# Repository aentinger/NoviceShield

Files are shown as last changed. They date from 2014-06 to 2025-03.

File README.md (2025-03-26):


💾 Novice Shield
================



# 📸 Image

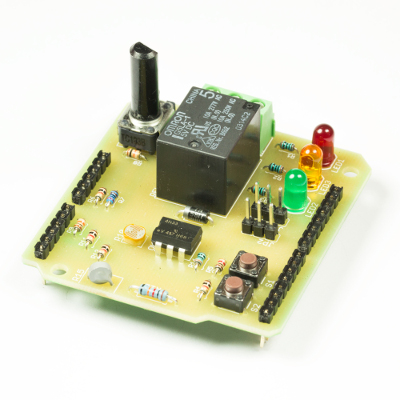
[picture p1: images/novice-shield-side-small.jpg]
LXRobotics P13 Novice Shield


# 📂 Description

The LXRobotics Novice Shield was developed to provide Arduino beginners with a smooth introduction of how to interface various sensors/actuators with an Arduino. This is achieved by providing actuators and sensors frequently encountered in Arduino applications such as light sensors, temperature sensors, switches, relays, potentiometers, LEDs etc. Numerous sample programs illustrate how the respective sensors or actuators can be controlled.

**Features**

* LED traffic light system consisting of red, yello and green LED
* 2 push buttons
* 2 RC servo connectors for controlling RC servos
* Fixed and variable voltage divider
* Light sensor (Light Dependent Resistor)
* 2 Temperature sensors: PTC und NTC
* Relay with Optocoupler
* Relay facts:
  * Max. current: 10 A
  * Max. DC voltage: 24 V DC
  * Max. AC voltage: 250 V AC
  * Relay-Typ: SPDT (Single Pole commutator)
* Numerous example program

# 🎥 [Video](images/novice_shield_demo.mp4)

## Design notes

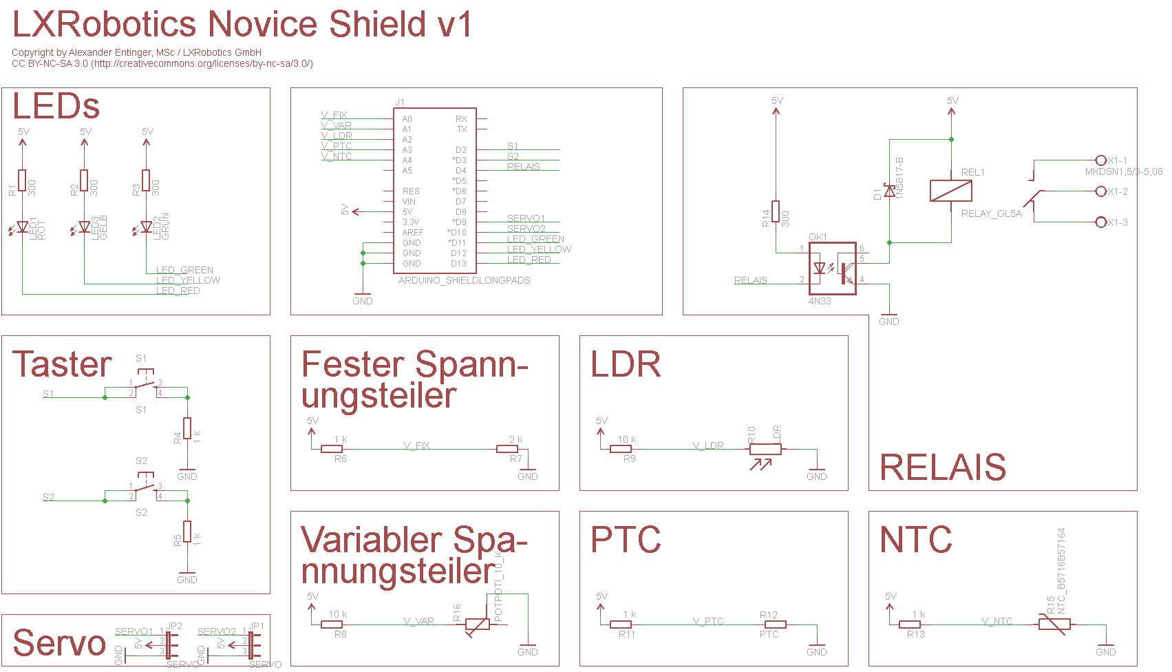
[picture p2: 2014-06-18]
hardware/lxr_novice_shield_v1.png

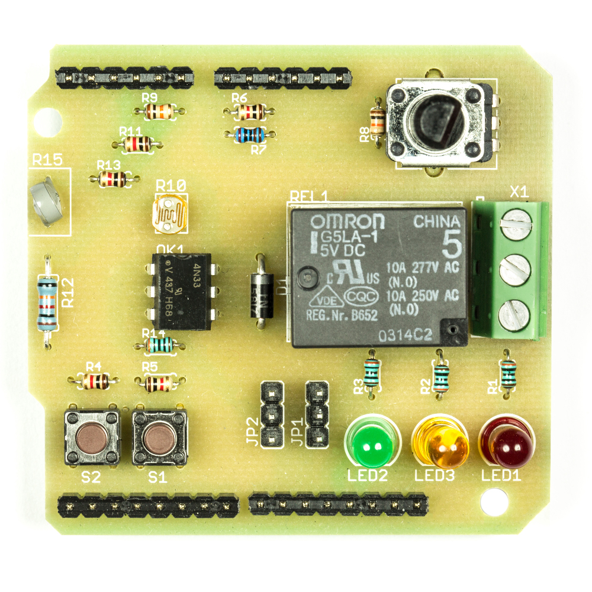
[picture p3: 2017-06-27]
images/novice-shield-top-large.jpg

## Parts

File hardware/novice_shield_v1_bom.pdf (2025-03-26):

Menge | Schaltplan | Bezeichnung | Farnell Bestell Nummer | Preis (1 Stück) | Gesamtpreis | Wird bestückt | Footprint | Säckchen | ESD
1 | LED1 | LED Rot, 5 mm, 10 mA, 1.9 V | 1003211 | € 0,19 | € 0,19 | | | S3 | x
1 | LED2 | LED Grün, 5 mm, 10 mA, 2.1 V | 1003214 | € 0,20 | € 0,20
1 | LED3 | LED Gelb, 5 mm, 10 mA, 2 V | 1003217 | € 0,15 | € 0,15
4 | R1,R2,R3,R14 | Widerstand, 300 R, 0.25 W, Durchsteck | 2329916 | € 0,03 | € 0,13 | | | S1 | x
2 | S1,S2 | Taster, Durchsteckmontage, 5 mm | 9471707 | € 0,10 | € 0,20 | | | S2
5 | R4,R5,R6,R11,R13 | Widerstand, 1k, 0.125 W, Durchsteck | 1700237 | € 0,01 | € 0,07 | | | S1 | x
1 | R7 | Widerstand, 2k, 0.125 W, Durchsteck | 9342788 | € 0,03 | € 0,03
1 | R16 | Drehpotentiometer, 10k | 1191725 | € 2,79 | € 2,79
1 | R10 | LDR, VT935G | 1652638 | € 0,36 | € 0,36
2 | R8,R9 | Widerstand, 10k, 0.125 W, Durchsteck | 1700251 | € 0,01 | € 0,03
2 | JP1,JP2 | Stiftleiste, 3x1, 2.54 mm | 1022249 | € 0,19 | € 0,38 | | | S2
1 | R12 | Widerstand, PTC, 1 k, Durchsteck | 1174306 | € 0,42 | € 0,42 | | | S1 | x
1 | R15 | Widerstand, NTC, 1 k, Durchsteck | 9753419 | € 0,85 | € 0,85
1 | REL1 | GL5A Leistungsrelais, 5 VDC, 250 V AC, 10 A, RCOIL = 70 R | 1455502 | € 1,43 | € 1,43 | | | S2
1 | OK1 | 4N33, Optokoppler mit Photo-Darlington, DIL06 | 1469601 | € 0,45 | € 0,45 | | | S3
1 | D1 | 1N5817, Diode Shottkey, If=1A, Ur=20V | 1458990 | € 0,30 | € 0,30 | | | S1 | x
1 | X1 | Schraubklemme 3-Polig, MKDSN1.5/3-5.08 | 3041451 | € 1,42 | € 1,42 | | | S2
1 | J1 | Arduino Stiftleistenset (Stecker lang) | ELV | € | 0,75 | € | 0,75 | - | http://www.elv.at/buchsenleisten-set-fuer-arduino-boards.html
1 | | Leitfähiger Schaumstoff | 1687855 | € | 2,40 | € | 2,40 | - | Bestellung von 1 Stück für 50 Novice Shields ausreichend
| | | | Summe | | € | 12,55

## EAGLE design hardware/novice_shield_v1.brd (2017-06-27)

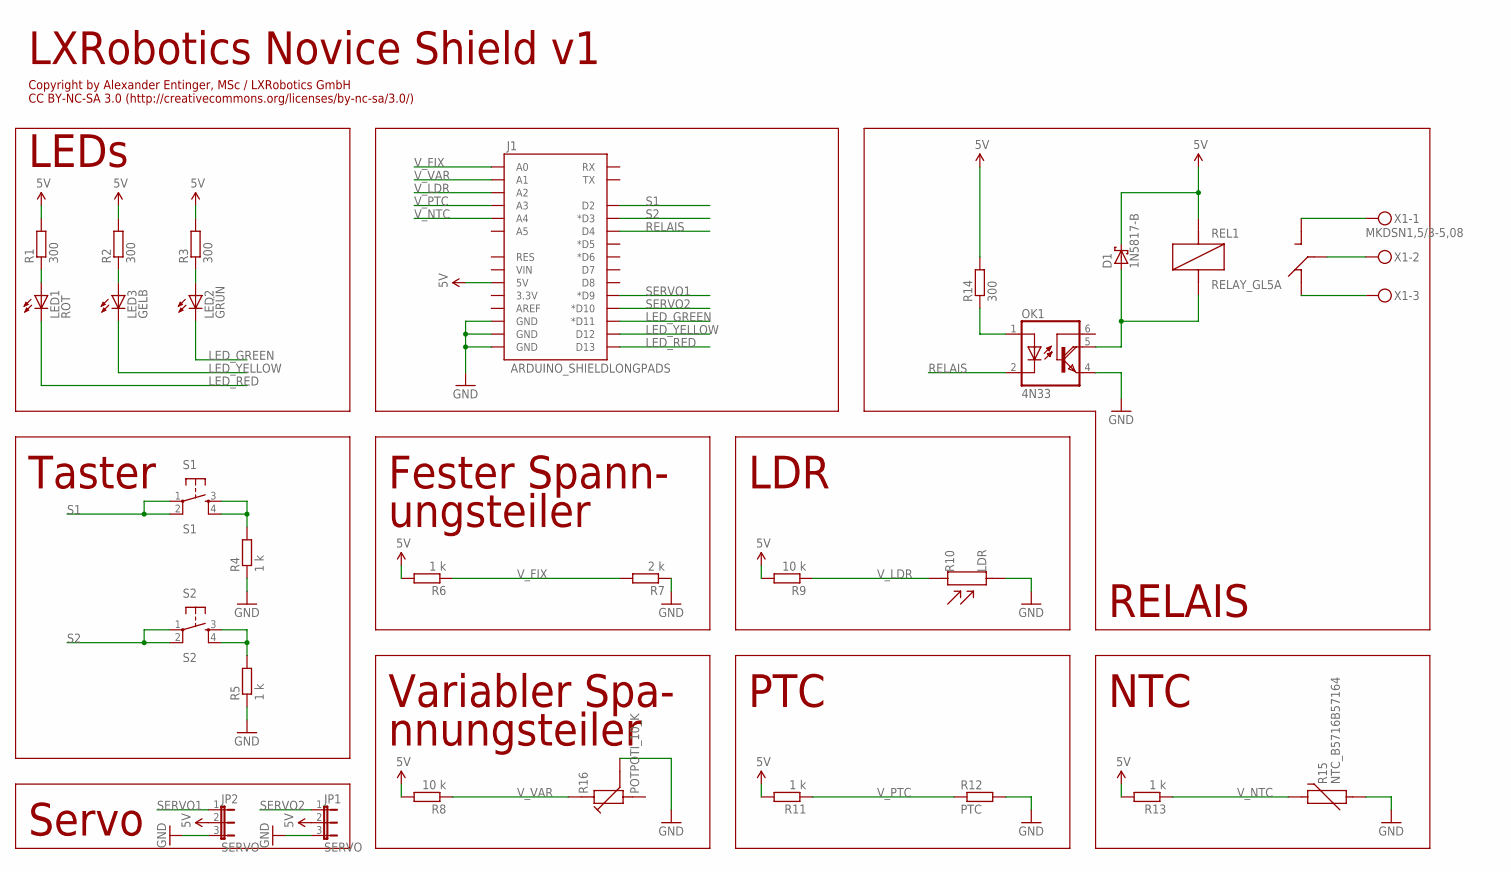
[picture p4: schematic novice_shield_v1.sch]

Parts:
D1: 1N5817-B; DO41-7.6
J1: ARDUINO_SHIELDLONGPADS; DUEMILANOVE_SHIELD_LONGPADS
JP1, JP2: SERVO; JP2
LED1: ROT; LED5MM
LED2: GRÜN; LED5MM
LED3: GELB; LED5MM
OK1: 4N33; DIL06
R1, R2, R3, R14: 300; 0204/5
R4, R5, R6, R11, R13: 1 k; 0204/5
R7: 2 k; 0204/5
R8, R9: 10 k; 0204/5
R10: LDR
R12: PTC; 0207/10
R15: NTC_B5716B57164; NTC_5MM_RADIAL
R16: POTPOTI_10_K; POT_10K
REL1: RELAY_GL5A
S1: S1; TACTILE-PTH
S2: S2; TACTILE-PTH
X1: MKDSN1,5/3-5,08

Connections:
5V: D1.C, J1.5V, JP1.2, JP2.2, R1.2, R2.2, R3.2, R6.2, R8.2, R9.2, R11.2, R13.2, R14.2, REL1.R2 (R2_COIL1)
GND: J1.GND@0 (GND), J1.GND@1 (GND), J1.GND@2 (GND), JP1.3, JP2.3, OK1.4 (E), R4.1, R5.1, R7.1, R10.P$2, R12.2, R15.P$2 (2), R16.VAR
LED_GREEN: J1.D11 (*D11), LED2.K (C)
LED_RED: J1.D13, LED1.K (C)
LED_YELLOW: J1.D12, LED3.K (C)
unnamed: LED1.A, R1.1
unnamed: LED3.A, R2.1
unnamed: LED2.A, R3.1
unnamed: R4.2, S1.3, S1.4
unnamed: R5.2, S2.3, S2.4
unnamed: REL1.R4 (R4_SW), X1.3
unnamed: REL1.R1 (R1_COMMON), X1.2
unnamed: REL1.R3 (R3_SW), X1.1
unnamed: OK1.1 (A), R14.1
unnamed: D1.A, OK1.5 (COL), REL1.R5 (R5_COIL2)
RELAIS: J1.D4, OK1.2 (C)
S1: J1.D2, S1.1, S1.2
S2: J1.D3 (*D3), S2.1, S2.2
SERVO1: J1.D9 (*D9), JP2.1
SERVO2: J1.D10 (*D10), JP1.1
V_FIX: J1.A0, R6.1, R7.2
V_LDR: J1.A2, R9.1, R10.P$1
V_NTC: J1.A4, R13.1, R15.P$1 (1)
V_PTC: J1.A3, R11.1, R12.1
V_VAR: J1.A1, R8.1, R16.S

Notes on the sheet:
LEDs
Taster
Fester Spann-
ungsteiler
Variabler Spa-
nnungsteiler
LDR
Servo
PTC
NTC
RELAIS
LXRobotics Novice Shield v1
Copyright by Alexander Entinger, MSc / LXRobotics GmbH CC BY-NC-SA 3.0 (http://creativecommons.org/licenses/by-nc-sa/3.0/)

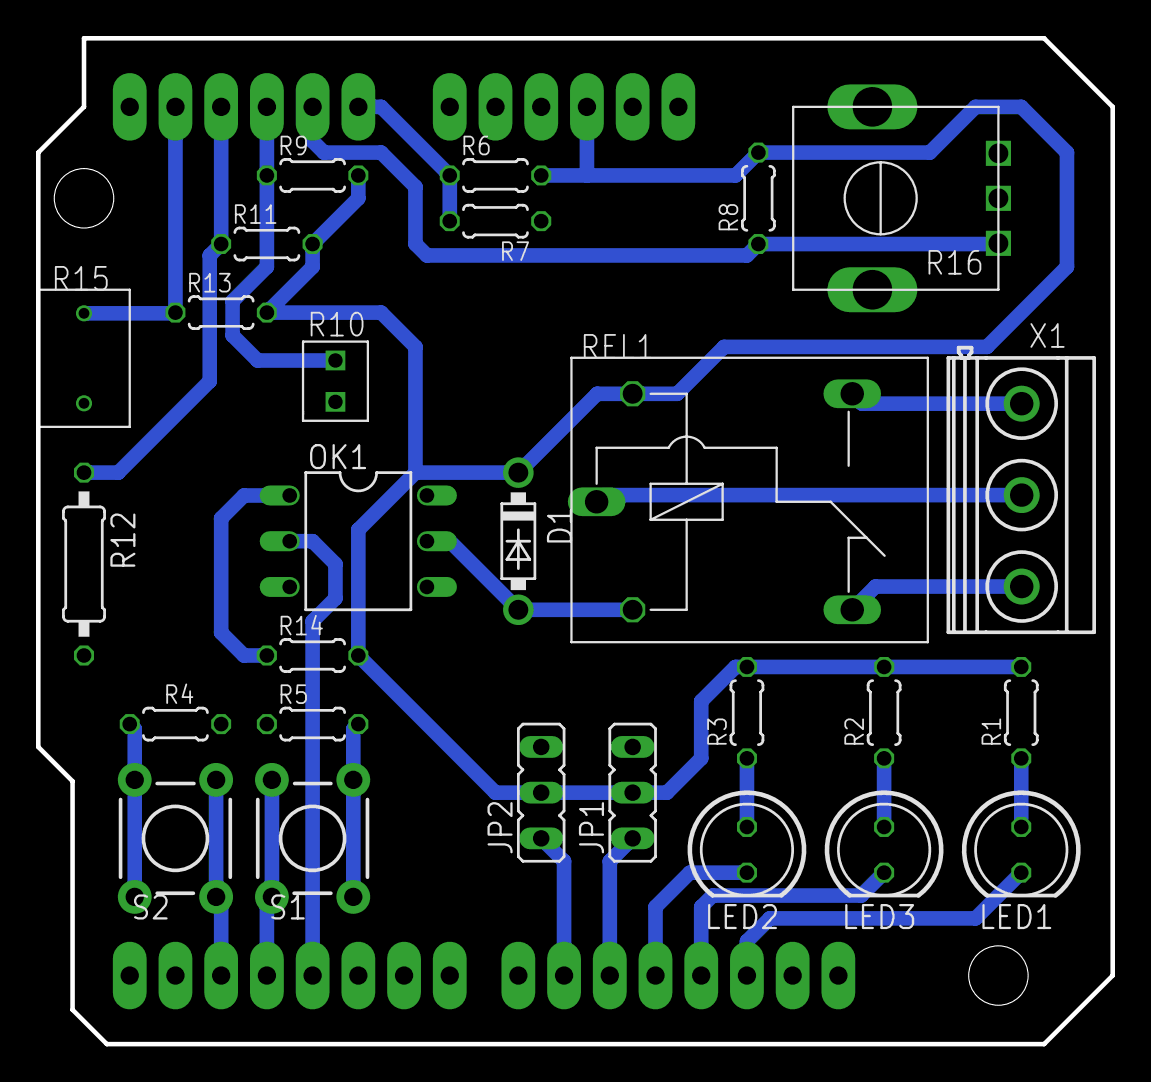
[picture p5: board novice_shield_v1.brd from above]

Board: 2 copper layers, 59.7 x 55.9 mm, 28 parts (0 on the bottom side), 25 nets.

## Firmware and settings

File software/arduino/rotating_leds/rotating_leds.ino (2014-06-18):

/**
 * @author Alexander Entinger, MSc / LXRobotics
 * @brief this sketch demonstrates how to control the leds of the LXRobotics Novice Shield
 * @file rotating_leds.ino
 */

static int const led_green_pin = 11; // D11
static int const led_yellow_pin = 12; // D12
static int const led_red_pin = 13; // D13

void setup() {
  // configure the led pins as outputs
  pinMode(led_green_pin, OUTPUT);
  pinMode(led_yellow_pin, OUTPUT);
  pinMode(led_red_pin, OUTPUT);
  // turn of the leds
  turn_off_red();
  turn_off_yellow();
  turn_off_green();
}

void turn_on_red() {
  digitalWrite(led_red_pin, LOW);
}
void turn_off_red() {
  digitalWrite(led_red_pin, HIGH);
}
void turn_on_yellow() {
  digitalWrite(led_yellow_pin, LOW);
}
void turn_off_yellow() {
  digitalWrite(led_yellow_pin, HIGH);
}
void turn_on_green() {
  digitalWrite(led_green_pin, LOW);
}
void turn_off_green() {
  digitalWrite(led_green_pin, HIGH);
}

void loop() {
  turn_off_green();
  turn_on_red();
  delay(100);
  turn_on_yellow();
  turn_off_red();
  delay(100);
  turn_on_green();
  turn_off_yellow();
  delay(100);
}

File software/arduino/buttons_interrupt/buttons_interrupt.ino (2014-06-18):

/**
 * @author Alexander Entinger, MSc / LXRobotics
 * @brief this sketch demonstrates how to read the button state and display it on the leds using a method known as "interrupt"
 * @file buttons_interrupt.ino
 */

static int const s1_pin = 2; // D2
static int const s2_pin = 3; // D3
static int const led_green_pin = 11; // D11
static int const led_yellow_pin = 12; // D12
static int const led_red_pin = 13; // D13

void setup() {
  // configure the two button pins as input with pullup
  pinMode(s1_pin, INPUT_PULLUP);
  pinMode(s2_pin, INPUT_PULLUP);
  // configure the led pins as outputs
  pinMode(led_green_pin, OUTPUT);
  pinMode(led_yellow_pin, OUTPUT);
  pinMode(led_red_pin, OUTPUT);
  digitalWrite(led_green_pin, HIGH);
  digitalWrite(led_yellow_pin, HIGH);
  digitalWrite(led_red_pin, HIGH);
  // attach the interrupt handler functions
  attachInterrupt(0, &isr_s1, CHANGE); // call function isr_s1 whenever a change edge is detected at s1 (connected to D2 = INT0)
  attachInterrupt(1, &isr_s2, CHANGE); // call function isr_s2 whenever a change is detected at s1 (connected to D3 = INT1)
}

// this function is called whenever a change at the pin INT0 = D2 = S1 occurs
void isr_s1() {
  boolean const s1_pressed = digitalRead(s1_pin) == LOW;
  if(s1_pressed) {
    digitalWrite(led_green_pin, LOW); 
  } 
  else {
    digitalWrite(led_green_pin, HIGH); 
  }
}

// this function is called whenever a change at the pin INT1 = D3 = S2 occurs
void isr_s2() {
  boolean const s2_pressed = digitalRead(s2_pin) == LOW;
  if(s2_pressed) {
    digitalWrite(led_red_pin, LOW); 
  } 
  else {
    digitalWrite(led_red_pin, HIGH); 
  }
}

void loop() {
  // dont do anything here - everything is handled within the interrupt service routine
}

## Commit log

2014-06-18 checking in initial demo examples and schematic
2017-06-27 Adding hardware + images
    [novice_shield_v1.brd, novice_shield_v1.sch]
2025-03-26 Upload BOM.

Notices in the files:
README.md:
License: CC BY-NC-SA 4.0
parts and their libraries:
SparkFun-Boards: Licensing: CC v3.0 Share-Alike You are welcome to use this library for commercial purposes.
